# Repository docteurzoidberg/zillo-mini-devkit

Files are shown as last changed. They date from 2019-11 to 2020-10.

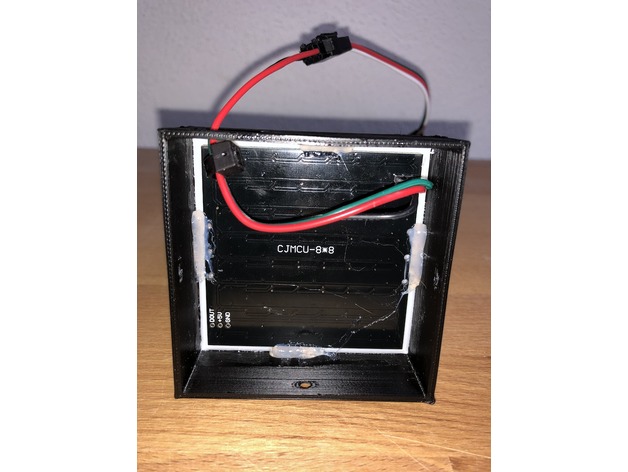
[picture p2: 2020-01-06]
stl/3D_RGB_DreamLight/images/47f5d1adb31408fe70bcf815f70e909c_preview_featured.jpg

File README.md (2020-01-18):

# Bataille des artisans v1: Le mini zillo-mini-devkit !

### code/

des exemple de projets (programmes) PIO pour le zillo-mini-devkit

(ajoutés au fur et a mesure des epreuves)

### doc/

les docs (pdfs, images, markdown)

### kicad/

schema et pcb Kicad

### scad

fichiers source openscad du boitier

### stl: fichiers 3d

pour impression 3d ou autre

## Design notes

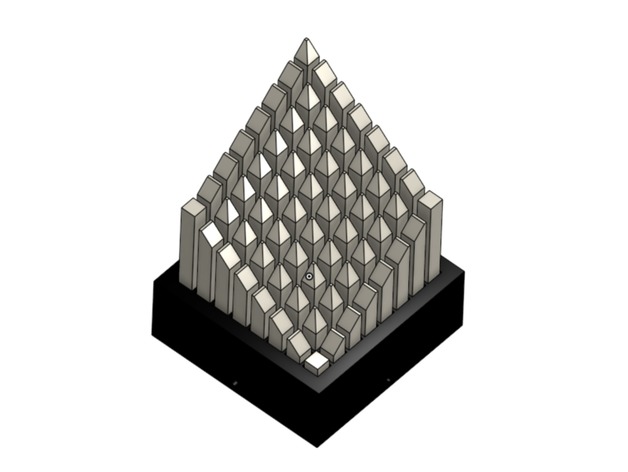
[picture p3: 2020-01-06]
stl/3D_RGB_DreamLight/images/6edd8dbd0c24616a28d37a252afb0a28_preview_featured.jpg

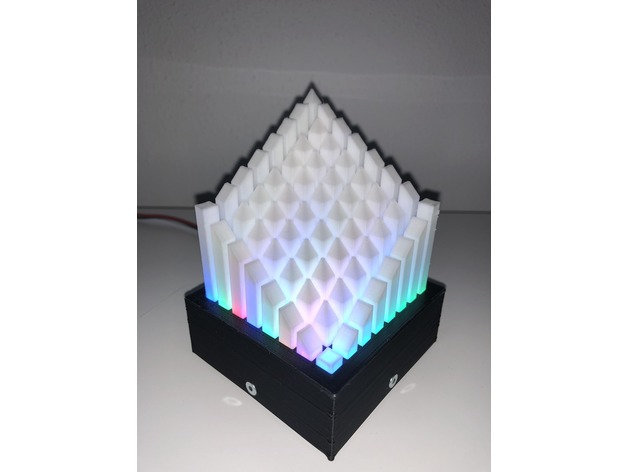
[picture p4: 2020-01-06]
stl/3D_RGB_DreamLight/images/e4f85dc79a4a61ff5d579b9ad5ff1216_preview_featured.jpg

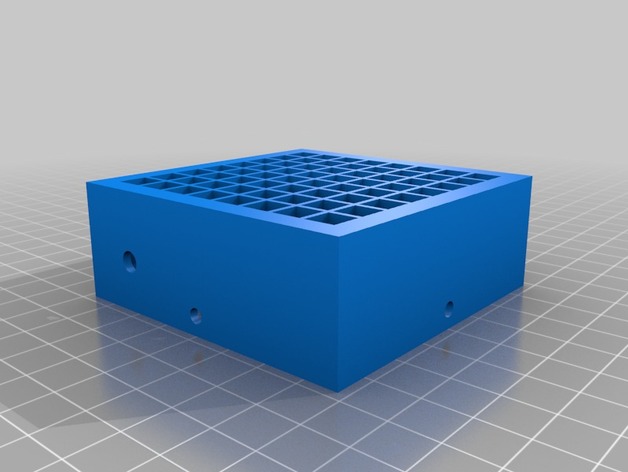
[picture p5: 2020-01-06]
stl/3D_RGB_DreamLight/images/f91d5b55845ccc286b120ae7885c4f8a_preview_featured.jpg

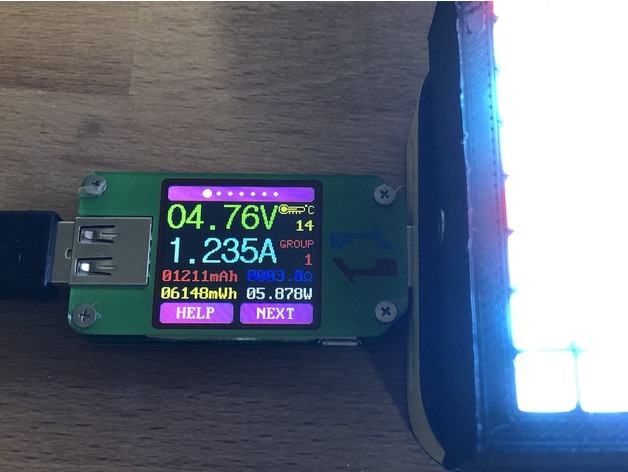
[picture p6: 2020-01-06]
stl/3D_RGB_DreamLight/images/61bdb1df734638b5d98c2c8067bef4ee_preview_featured.jpg

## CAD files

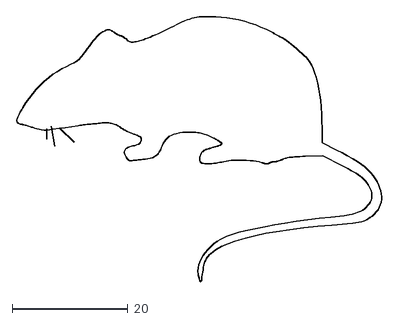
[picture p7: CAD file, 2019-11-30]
kicad/artworks/rat.dxf
63.2 x 45.9

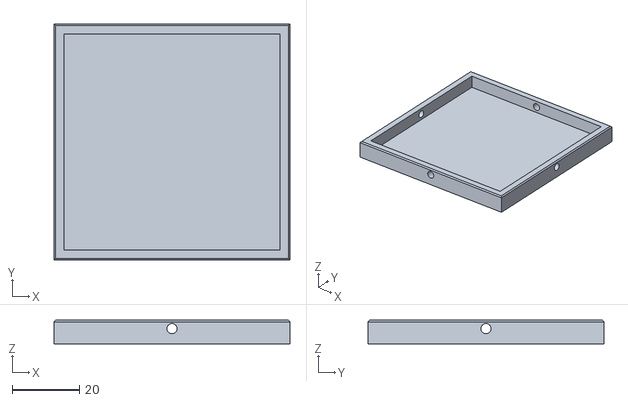
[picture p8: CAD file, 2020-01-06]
stl/3D_RGB_DreamLight/files/Bottom_CoverV2_noLogo.stl
70.0 x 70.0 x 7.00

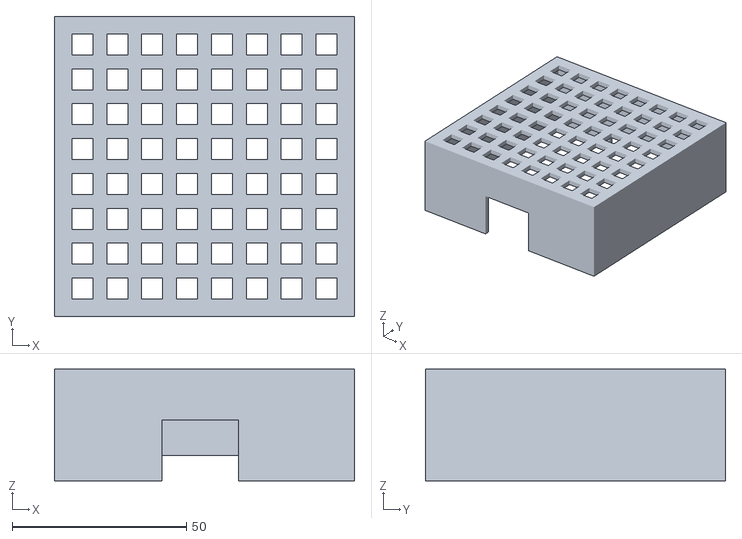
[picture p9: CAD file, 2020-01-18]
stl/test_body_v1.1.stl
86.0 x 86.0 x 32.0

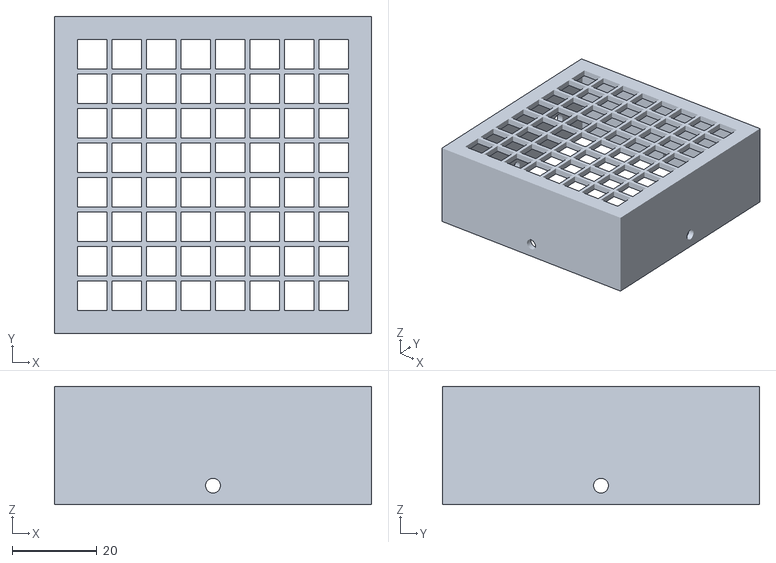
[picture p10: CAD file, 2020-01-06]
stl/3D_RGB_DreamLight/files/Top_CoverV2_6mm.stl
75.0 x 75.0 x 28.0

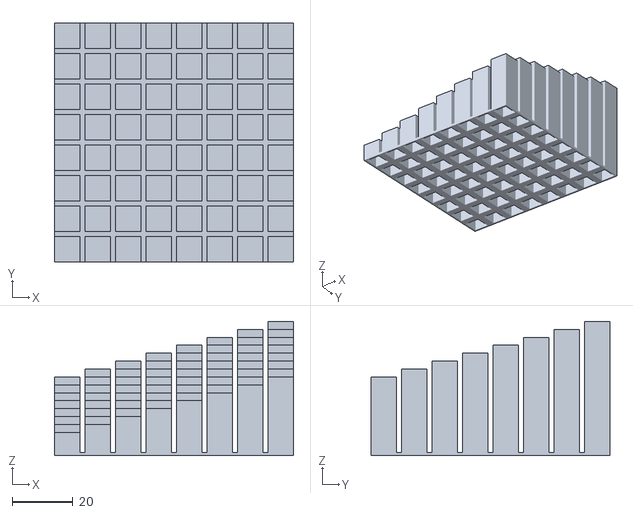
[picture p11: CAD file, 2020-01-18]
stl/test_diffuser_v1.stl
78.4 x 78.4 x 44.0

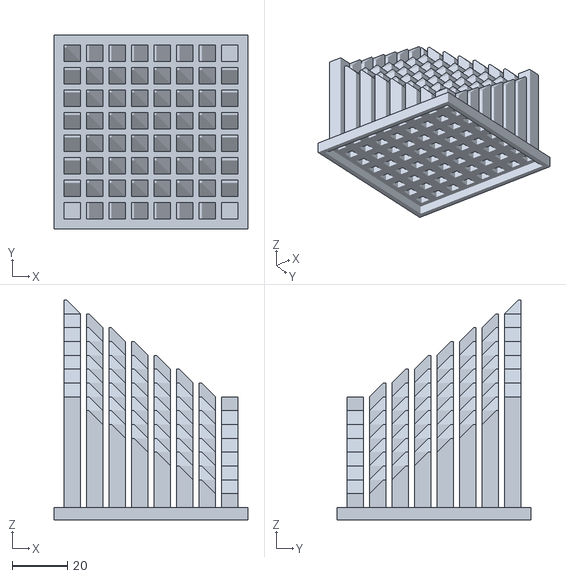
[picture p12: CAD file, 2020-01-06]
stl/3D_RGB_DreamLight/files/Towers_6mm_shell.stl
70.0 x 70.0 x 79.5

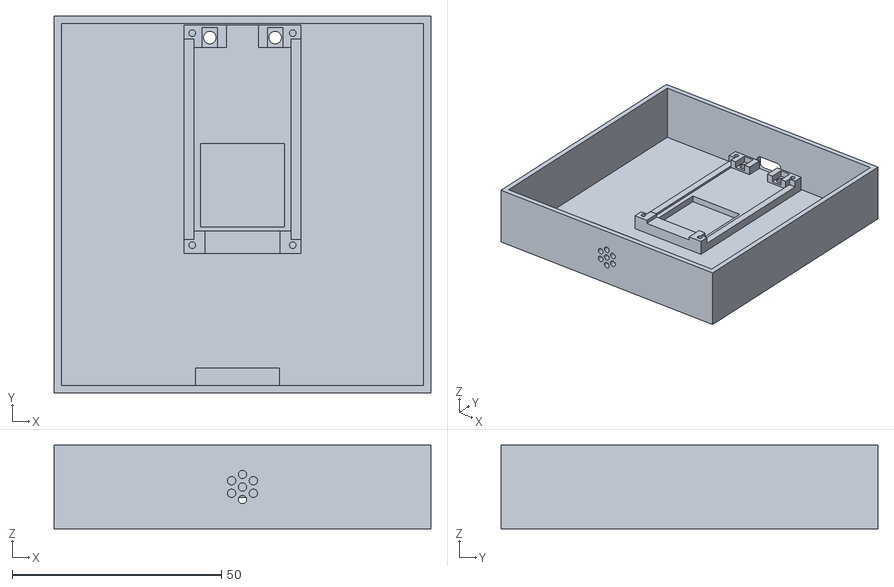
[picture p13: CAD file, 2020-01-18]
stl/test_bottom_v1.1.stl
90.0 x 90.0 x 20.0

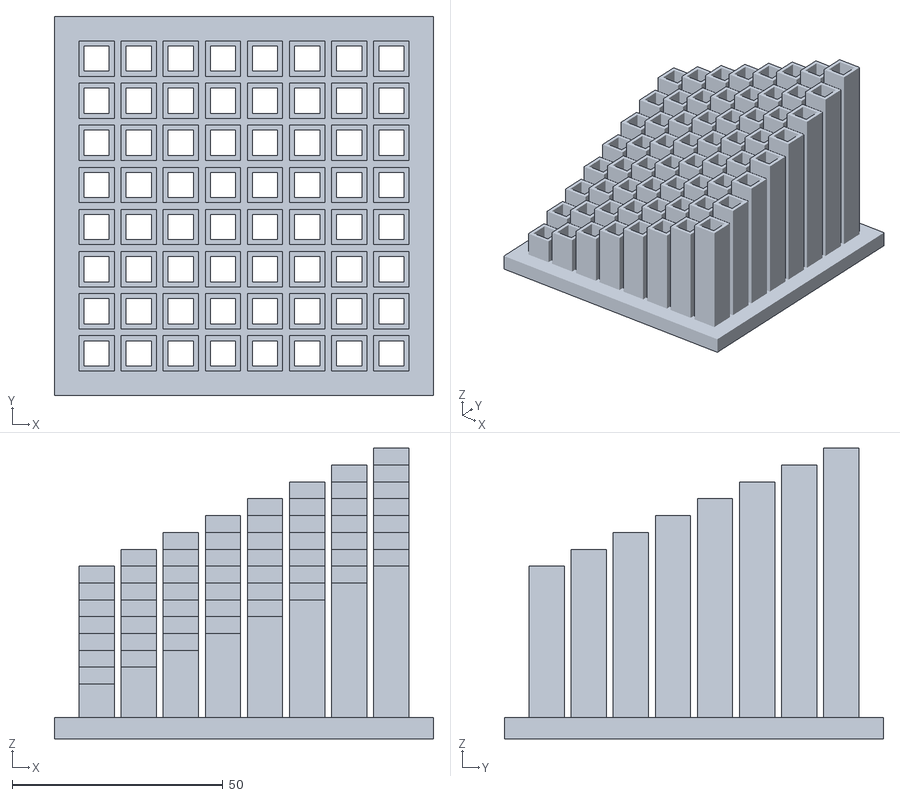
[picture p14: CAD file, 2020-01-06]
stl/diffuser.stl
90.0 x 90.0 x 69.0

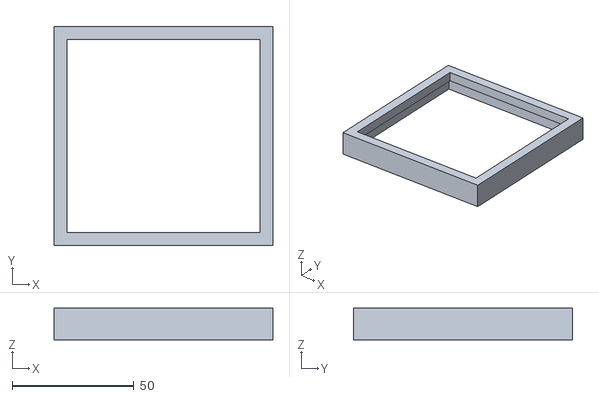
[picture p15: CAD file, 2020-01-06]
stl/top.stl
90.0 x 90.0 x 13.0

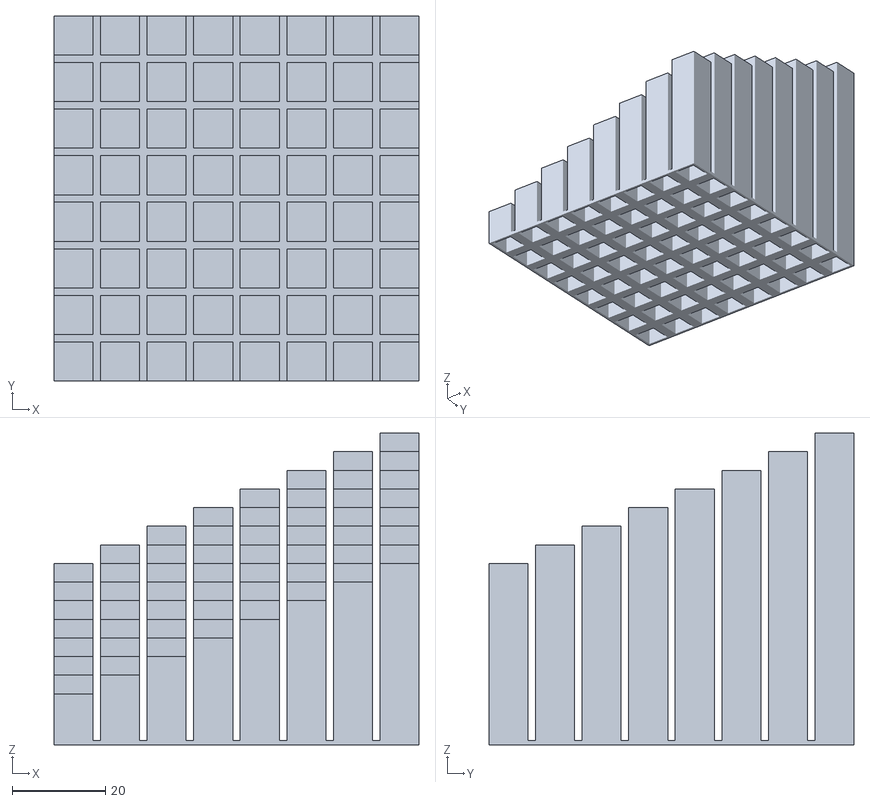
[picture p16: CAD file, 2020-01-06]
stl/test_diffuser_large.stl
78.4 x 78.4 x 67.0

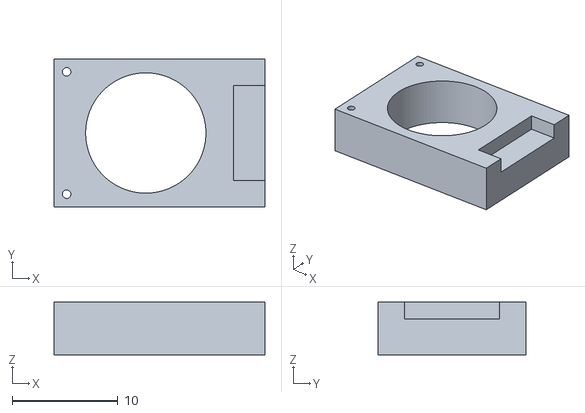
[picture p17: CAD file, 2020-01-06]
stl/test_support_micro.stl
20.0 x 14.0 x 5.00

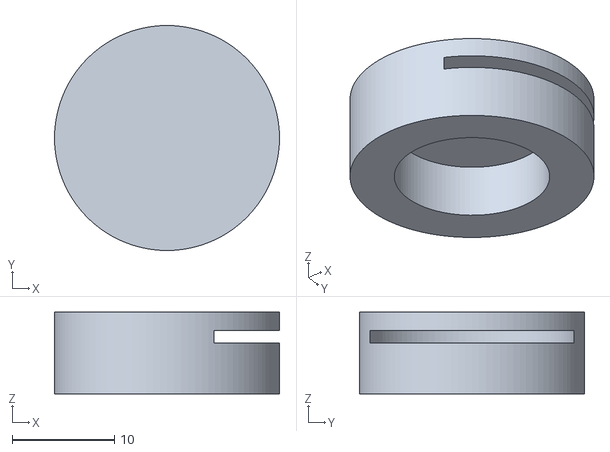
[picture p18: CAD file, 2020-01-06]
stl/test_support_skpdisque.stl
22.0 x 22.0 x 8.00

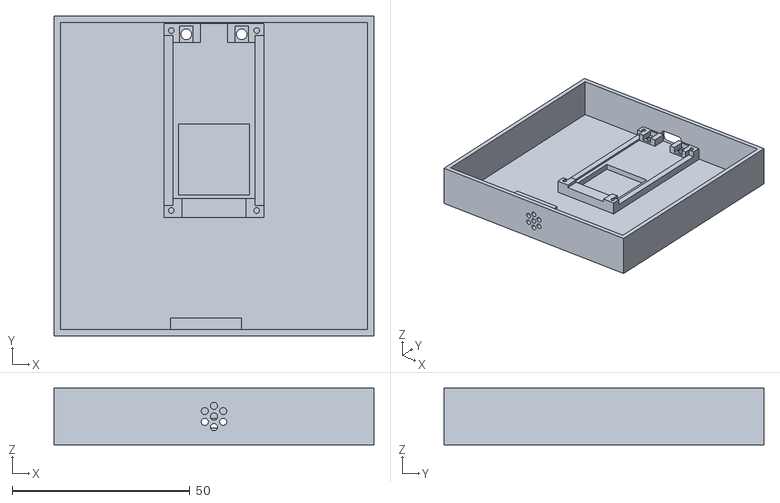
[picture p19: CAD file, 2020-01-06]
stl/bottom.stl
90.0 x 90.0 x 16.0

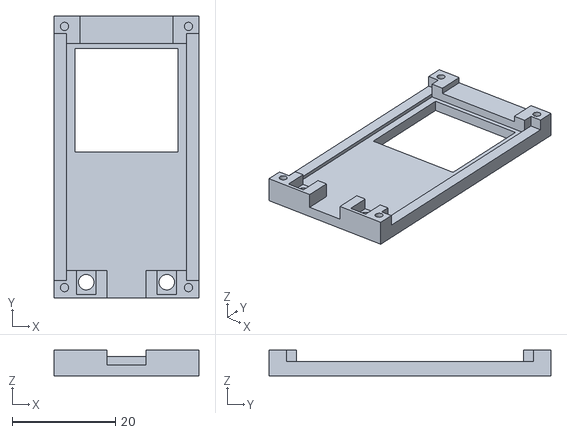
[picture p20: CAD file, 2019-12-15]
stl/test_support_esp.stl
28.0 x 54.6 x 5.00

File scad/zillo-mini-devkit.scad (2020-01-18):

//matrice leds
leds_x=8;
leds_y=8;
led_spacing=10;
grid_h=2;
led_l=6;
led_w=6;
matrix_length=leds_x*led_spacing;
matrix_width=leds_y*led_spacing;

//fond
socle_walls=2;
socle_l=socle_walls+1+matrix_length+1+socle_walls;
socle_w=socle_walls+1+matrix_width+1+socle_walls;
socle_h=32;
bottom_walls=1;
bottom_l=socle_l+(bottom_walls*2)+2;
bottom_w=socle_w+(bottom_walls*2)+2;

//diffuseur
diffuser_walls=bottom_walls;
diffuser_l=socle_l+(diffuser_walls*2)+2;
diffuser_w=socle_w+(diffuser_walls*2)+2;
diffuser_h=16;
diffuser_shell=8;

//forme esp32
esp32_epaisseurpcb=1.6;
btnbodyl=3.92;
btnbodyw=2.96;
btnbodyh=1.8;
pcbw=28;
pcbl=54.6;

//support micro
diamic=11.4;
lmic=20;
wmic=14;
hmic=5;

diaspk=20;
hspk=1;
hsupportspk=8;
diasupportspk=22;
bottom_h=20;

//validé: correspond parfait a la matrice!
module grid(){
	firstled_x=socle_walls;
	firstled_y=socle_walls;
	difference(){
		cube([matrix_width,matrix_length,grid_h]);
		for(x=[0:leds_x-1]){
			for(y=[0:leds_y-1]){
				posx=firstled_x+(x*led_spacing);
				posy=firstled_y+(y*led_spacing);
				translate([posx,posy,-.1])
					cube([led_l,led_w,6]);
			}
		}
	}
}

module bodydecoupe() {
	//decoupe support pcb
	translate([socle_l/2,socle_w,6.6/2])
		cube([pcbw+2,20,8],center=true);
	
	//decoupe support micro
	translate([bottom_l/2 -2-1.2,0,(wmic+2)/2 -.1])
		cube([lmic+2,20,(bottom_h-wmic)/2 +    wmic+2+.1],center=true);
}

module body() {
	difference() {
		union() {
			
			//shell cube
			difference(){
				cube([socle_l,socle_w,socle_h]);
				translate([socle_walls+1,socle_walls+1,-.1])
					cube([socle_l-socle_walls*2-2,socle_w-socle_walls*2-2,socle_h+.2]);
				//FIX: forcait sur le pcb, diminution a l'arrache des cotes interieurs
				translate([socle_walls,socle_walls,-.1])
					cube([socle_l-socle_walls*2+.4,socle_w-socle_walls*2+.4,socle_h-grid_h]);
			}
			
			//grille matrice
			translate([socle_walls+1,socle_walls+1,socle_h-grid_h])
				grid();
		}
		
		//decoupes
		bodydecoupe();	
	}
}

//-----------------------------------------------------------------------------------

module colonne1(x=0,y=0,height=-1,shell=1.6,topstyle="flat"){
	
	//hauteur colonne
	h=(x+1)*2.6+(y+1)*2.6;
	
	//shell colonne
	difference() {
		cube([led_l+(shell*2),led_w+(shell*2),h]);
		translate([shell-0.4,shell-0.4,-.1])
			cube([led_l+0.8,led_w+0.8,h +.2]);
	}
	
	//toit plat
	translate([0,0,h])
		cube([led_l+(shell*2),led_w+(shell*2),1.4]);
}

module colonne2(x=0,y=0,height=-1,shell=0.6,topstyle="flat"){
	h=(x+1)*5+(y+1)*5;
	rc = (sqrt(3)/2)*5;
	ofX=((rc+2*shell)/2)+1/3;
	ofY=((rc+2*shell)/2)+1/3;
	translate([ofX,ofY])
	rotate([0,0,30])
	difference() {
		cylinder(h,rc+shell,rc+shell, $fn=6);
		translate([0,0,-.1])
			cylinder(h +.2,rc,rc, $fn=6);
	}
}

module top() {
	
	//shell cube accroche top
	difference(){
		cube([diffuser_l,diffuser_w,diffuser_shell]);
		translate([diffuser_walls+1-.2,diffuser_walls+1-.2,-.1])
			cube([diffuser_l-diffuser_walls*2-2+.4,diffuser_w-diffuser_walls*2-2+.4,diffuser_shell+.2]);
	}
	
	//shell cube diffuseur
	translate([0,0,diffuser_shell]) {
		difference() {
			cube([diffuser_l,diffuser_w,diffuser_walls+4]);
			translate([5.4,5.4,-.1])
				cube([diffuser_l-5.4*2,diffuser_w-5.4*2,diffuser_walls+4+.2]);
		}
	}
}

module diffuser(type="colonne1") {
	
	//base
	//difference(){
	//	cube([diffuser_l,diffuser_w,diffuser_shell]);
	//	translate([diffuser_walls+1-.2,diffuser_walls+1-.2,-.1])
	//		cube([diffuser_l-diffuser_walls*2-2+.4,diffuser_w-diffuser_walls*2-2+.4,diffuser_shell+.2]);
	//}
	
	//trous base
	translate([0,0,diffuser_shell]) {
		difference(){
			translate([5.8,5.8,0])
			cube([diffuser_l-5.8*2,diffuser_w-5.8*2,diffuser_walls]);
			firstled_x=diffuser_walls+socle_walls+4;
			firstled_y=diffuser_walls+socle_walls+4;
			for(x=[0:leds_x-1]){
				for(y=[0:leds_y-1]){
					posx=firstled_x+(x*led_spacing);
					posy=firstled_y+(y*led_spacing);
					translate([posx-.4,posy-.4,-.1])
						cube([led_l+.8,led_w+.8,6]);
				}
			}
		}
	}
	
	//colonnes 
	colonnes_walls=1.2;
	translate([0,0,diffuser_shell+diffuser_walls]) {
		firstled_x=diffuser_walls+socle_walls+4;
		firstled_y=diffuser_walls+socle_walls+4;
		for(x2=[0:leds_x-1]){
			for(y2=[0:leds_y-1]){
				posx2=firstled_x+(x2*led_spacing);
				posy2=firstled_y+(y2*led_spacing);
				translate([posx2-colonnes_walls,posy2-colonnes_walls,0]) { 
					if(type=="colonne1")
						colonne1(x=x2,y=y2, shell=colonnes_walls);
					if(type=="colonne2")
						colonne2(x=x2,y=y2, shell=colonnes_walls);
				}
			}
		}
	}
}

//support vis esp32
module esp32_trouvis() {
	hauteurdecoupevis=esp32_epaisseurpcb+.2;
	diavis=2.4;
	
	cylinder(hauteurdecoupevis,diavis/2,diavis/2, $fn=30);
}

//boutons reset et boot de l'esp32
module esp32_bouton() {
	btnh=.2;
	btndia=1.2;
	
	color("gray")	
		translate([0,0,btnbodyh/2])
			cube([btnbodyw,btnbodyl,btnbodyh], center=true);
	color("black")
		translate([0,0,btnbodyh])
			cylinder(btnh,btndia,btndia, $fn=30);
}
 
//esp32 pour le preview
module esp32() {
	usbw=5.4;
	usbl=7;
	usbh=2;
	
	difference() {
		
	//pcb
		translate([0,0,1.6/2])
			color("green") cube([pcbw,pcbl,esp32_epaisseurpcb], center=true); 
		
	//trous pour les 4 vis
		//haut gauche
		translate([-(pcbw/2)+2,(pcbl/2)-2,-.1])
			esp32_trouvis();
		//haut droite
		translate([(pcbw/2)-2,(pcbl/2)-2,-.1])
			esp32_trouvis();
		//bas gauche
		translate([-(pcbw/2)+2,-(pcbl/2)+2,-.1])
			esp32_trouvis();
		//bas droite
		translate([(pcbw/2)-2,-(pcbl/2)+2,-.1])
			esp32_trouvis();
	}
	
	//port usb
	translate([0,-(pcbl/2)+(usbw/2)-1.6,esp32_epaisseurpcb+usbh/2])
		color("gray") cube([usbl,usbw,usbh], center=true); 
	
	//boutons
	translate([7.8,-(pcbl/2)+(btnbodyl/2)+1.8,esp32_epaisseurpcb])
		esp32_bouton();
	translate([-7.8,-(pcbl/2)+(btnbodyl/2)+1.8,esp32_epaisseurpcb])
		esp32_bouton();
	
	//module esp
	moduleh=3.6;
	modulew=15.2;
	modulel=17.2;
	translate([0,12,moduleh/2])
		cube([modulew,modulel,3],center=true);
}

//forme esp32 pour la decoupe (boutons plus large, clearances, pinheaders, etc)
module formedecoupe_esp32() {
	usbw=5.4;
	usbl=7.4;
	usbh=2.2;
	diavis=1.6;
	btndecoupeh=15;
	
	//pcb
	translate([0,0,esp32_epaisseurpcb/2])
		cube([pcbw,pcbl,esp32_epaisseurpcb], center=true); 
	
	//vis
		translate([-(pcbw/2)+2,(pcbl/2)-2,esp32_epaisseurpcb])
			cylinder(2,diavis/2,diavis/2, $fn=30);
		translate([(pcbw/2)-2,(pcbl/2)-2,esp32_epaisseurpcb])
			cylinder(2,diavis/2,diavis/2, $fn=30);
		translate([-(pcbw/2)+2,-(pcbl/2)+2,esp32_epaisseurpcb])
			cylinder(2,diavis/2,diavis/2, $fn=30);
		translate([(pcbw/2)-2,-(pcbl/2)+2,esp32_epaisseurpcb])
			cylinder(2,diavis/2,diavis/2, $fn=30);
		
	//usb
	translate([0,-(pcbl/2)+((usbw)/2)-1.6,esp32_epaisseurpcb+usbh/2])
		cube([usbl+.2,usbw*2,usbh+1.6], center=true); 
	
	//boutons
	translate([7.8,-(pcbl/2)+((btnbodyl+.2)/2)+1,esp32_epaisseurpcb]){
		translate([0,0,btnbodyh/2])
			cube([btnbodyw+.8,btnbodyl+.8,btnbodyh+1], center=true);
		translate([0,0,btnbodyh-.1])
			cylinder(btndecoupeh,3/2,3/2, $fn=30);
	}
	translate([-7.8,-(pcbl/2)+((btnbodyl+.2)/2)+1,esp32_epaisseurpcb]){
		translate([0,0,btnbodyh/2])
			cube([btnbodyw+.8,btnbodyl+.8,btnbodyh+1], center=true);
		translate([0,0,btnbodyh-.1])
			cylinder(btndecoupeh,3/2,3/2, $fn=30);
	}
	
	//module esp
	moduleh=5.2;
	modulew=20;
	modulel=20;
	translate([0,11,esp32_epaisseurpcb+moduleh/2])
		cube([modulew,modulel,moduleh],center=true);
	
	pinhdl=(2.54*19)-.4;
	pinhdw=2.40;
	pinhdh=2;
	
	//pins des pinheaders
	translate([-(pcbw/2)+pinhdw/2,0,esp32_epaisseurpcb+pinhdh/2])
		cube([pinhdw,pinhdl,pinhdh+.6],center=true);
	translate([(pcbw/2)-pinhdw/2,0,esp32_epaisseurpcb+pinhdh/2])
		cube([pinhdw,pinhdl,pinhdh+.6],center=true);
	
	//composants (simplifie)
	translate([0,0,esp32_epaisseurpcb+pinhdh/2])
		cube([pcbw-(2*pinhdw),pinhdl-4,pinhdh+2],center=true); 
	
	//pcb moduleesp (simplifie)
	translate([0,10,esp32_epaisseurpcb+0.5+.2])
		cube([18,pinhdl,1.2],center=true);
}

module support_esp32() {
	difference() {
		translate([0,0,5/2])
			cube([pcbw,pcbl,5], center=true);
		translate([0,0,5+esp32_epaisseurpcb+.1])
			rotate([0,180,0])
				formedecoupe_esp32();
	}
}

module cuberond(l,w,h) {
	translate([(-l+3)/2,(-w+3)/2,0])
	minkowski() {
		cube([l-3,w-3,h]);
		cylinder(h,3/2,3/2,$fn=100);
	}
}

module support_micro() {
	ofXmic=3+diamic/2;
	ofYmic=wmic/2;
	oftrou=1.2;
	diatrou=.8;
	wpins=3;
	lpins=9;
	
	difference() {
		cube([lmic,wmic,hmic]);
		translate([ofXmic,ofYmic,-.1])
			cylinder(hmic+.2,diamic/2,diamic/2, $fn=100);
		translate([oftrou,oftrou,-.1])
			cylinder(hmic+.2,diatrou/2,diatrou/2, $fn=100);
		translate([oftrou,wmic-oftrou,-.1])
			cylinder(hmic+.2,diatrou/2,diatrou/2, $fn=100);
		translate([lmic-wpins,(wmic-lpins)/2,hmic-1.6])
			cube([wpins,lpins,10]);
	}
}
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

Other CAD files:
stl/test_top.stl
stl/diffuser_small_square.stl
stl/test_diffuser_small.stl
stl/body.stl
stl/test_body.stl
stl/test_bottom.stl

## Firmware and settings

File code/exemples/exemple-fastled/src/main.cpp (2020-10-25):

#include <Arduino.h>
#include <SPI.h>
#include <Adafruit_GFX.h>
#include <FastLED.h>

#define LED_PIN     27
#define COLOR_ORDER GRB
#define CHIPSET     WS2812B
#define NUM_LEDS    3

#define BRIGHTNESS  50
#define FRAMES_PER_SECOND 60

CRGB leds[NUM_LEDS];

CRGB color;
void setup() {
  delay(3000); // sanity delay
  FastLED.addLeds<CHIPSET, LED_PIN, COLOR_ORDER>(leds, NUM_LEDS).setCorrection( TypicalLEDStrip );
  FastLED.setBrightness( BRIGHTNESS );
  color.r=255;
  color.g=255;
  color.b=255;
}

void loop()
{
  leds[0] = color;
  FastLED.show(); // display this frame
  FastLED.delay(1000 / FRAMES_PER_SECOND);
}

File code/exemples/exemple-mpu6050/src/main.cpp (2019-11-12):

#include <Adafruit_MPU6050.h>
#include <Adafruit_Sensor.h>
#include <Wire.h>

Adafruit_MPU6050 mpu;

void setup(void) {
  Serial.begin(115200);
  while (!Serial) {
    delay(10); // will pause Zero, Leonardo, etc until serial console opens
  }

  // Try to initialize!
  if (!mpu.begin()) {
    Serial.println("Failed to find MPU6050 chip");
    while (1) {
      delay(10);
    }
  }

  mpu.setAccelerometerRange(MPU6050_RANGE_16_G);
  mpu.setGyroRange(MPU6050_RANGE_250_DEG);
  mpu.setFilterBandwidth(MPU6050_BAND_21_HZ);
  Serial.println("");
  delay(100);
}

void loop() {
  /* Take a new reading */
  mpu.read();

  /* Get new sensor events with the readings */
  sensors_event_t a, g, temp;
  mpu.getEvent(&a, &g, &temp);

  /* Print out the values */
  Serial.print(a.acceleration.x);
  Serial.print(",");
  Serial.print(a.acceleration.y);
  Serial.print(",");
  Serial.print(a.acceleration.z);
  Serial.print(", ");
  Serial.print(g.gyro.x);
  Serial.print(",");
  Serial.print(g.gyro.y);
  Serial.print(",");
  Serial.print(g.gyro.z);
  Serial.println("");

  delay(10);
}

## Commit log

2019-11-12 esp32 pinout
2019-11-12 update pcb&schematic: i2c ok
    [zillo-mini-devkit.kicad_pcb, zillo-mini-devkit.sch]
2019-11-12 update readme: pics pcb
2019-11-12 scad: diffuseur
    [zillo-mini-devkit.scad]
2019-11-12 scad: bottom
    [zillo-mini-devkit.scad]
2019-11-30 kicad final
    [rat.dxf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]
2019-12-14 tests support esp32
    [libsupportpcb.scad]
2019-12-14 tests support esp32 stl
    [test_supportesp.stl]
2019-12-14 integration support dans piece bottom
    [bottom.stl, test_bottomwithsupport.stl, zillo-mini-devkit.scad]
2019-12-15 validation support
    [test_supportesp.stl, zillo-mini-devkit.scad]
2019-12-15 validation bottom + support
    [test_bottomwithsupport.stl, test_supportesp.stl, zillo-mini-devkit.scad]
2019-12-20 rm libsupportpcb
    [libsupportpcb.scad]
2020-01-18 fix boitier
    [test_body_v1.1.stl, test_bottom_v1.1.stl, test_diffuser_v1.stl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]
